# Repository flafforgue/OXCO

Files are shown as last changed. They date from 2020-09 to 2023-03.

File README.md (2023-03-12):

# OXCO
Kicad project for 10MHz OXCO with frequency divider and multiplier
outputs 25 Mhz, 10 Mhz, 1 Mhz, 10 Khz,1 kHz ( yes 100khz is ommited but i have not enougth space on board :) 

there are 4 x 10 Mhz outputs , grouped by 2 in oposite phase
what can be done is for 2 installing filter as indicated and for the two other replacing inductance 
and output capacity by strap and not installing filter capacity for having square waves output.

composed of 2 boards
first with OXCO and precision voltage generator and buffered 10 MHz outputs
second with ICS511 multiplier ( 2.5 so 25 MHz outputs ) and 74LS390  dividers

all outputs are 50 Ohms, buffered with 3 x 74HC04 inverter and filter to keep only sine wave



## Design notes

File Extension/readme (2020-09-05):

extention board with dividers and multiplier module

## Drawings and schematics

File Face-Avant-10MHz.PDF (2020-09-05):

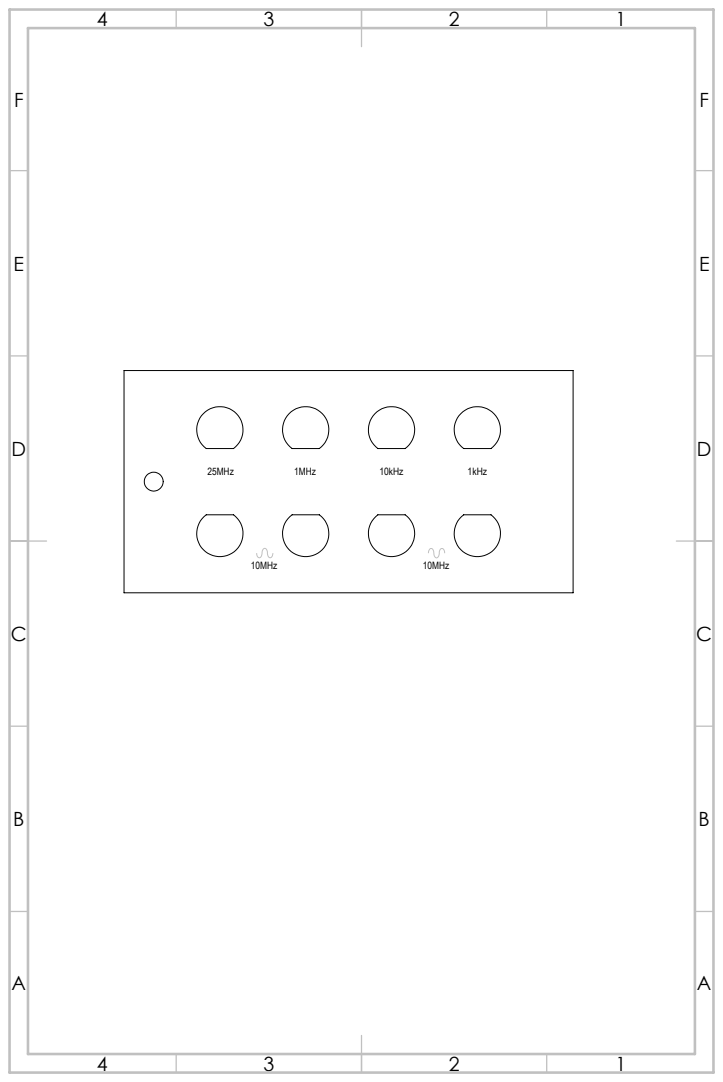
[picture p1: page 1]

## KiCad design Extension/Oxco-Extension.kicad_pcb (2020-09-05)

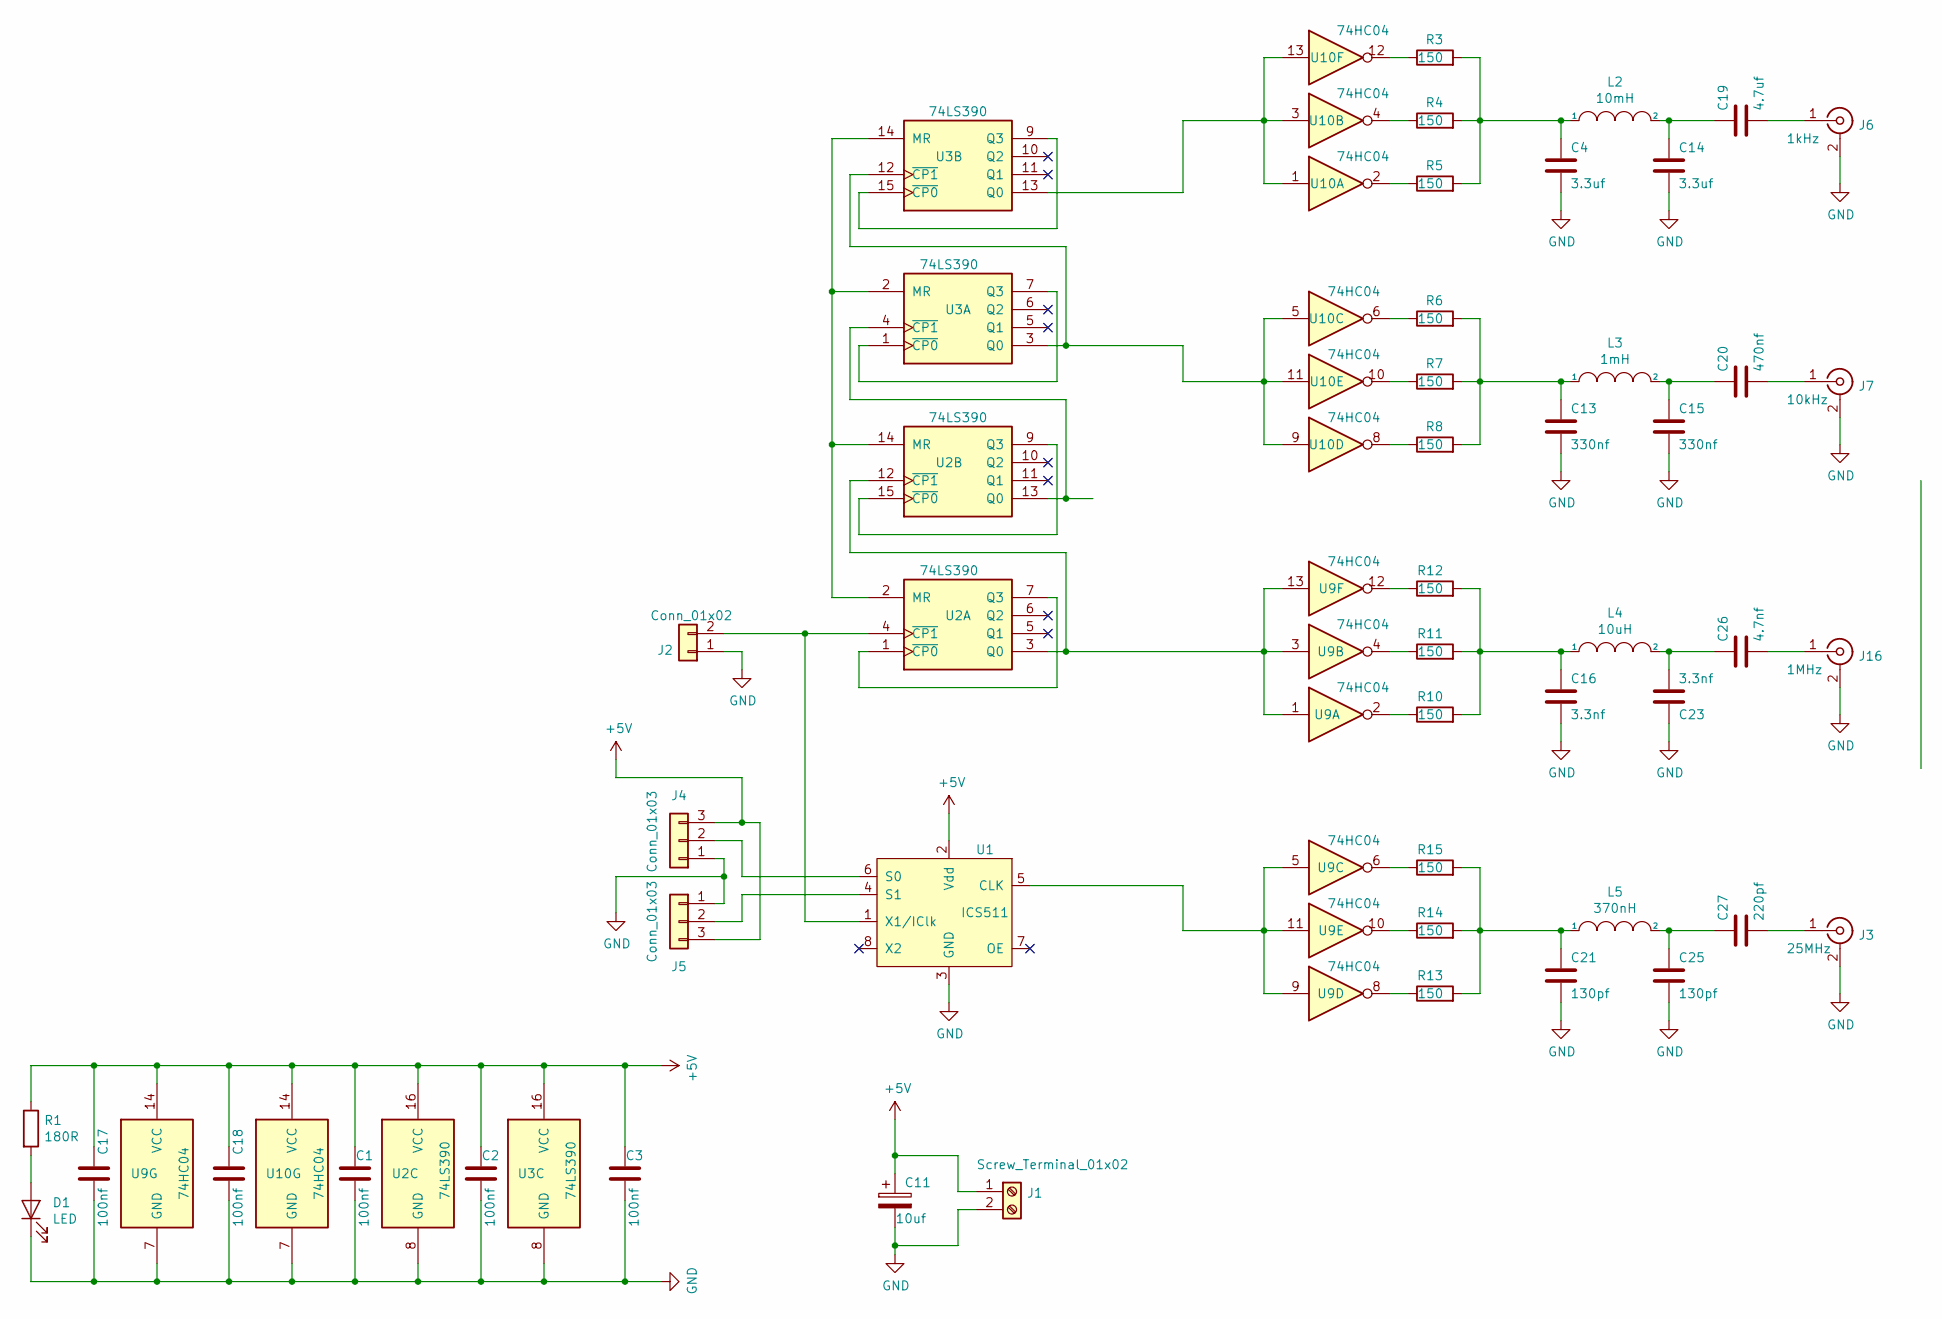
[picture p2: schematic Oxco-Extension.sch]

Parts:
C1, C2, C3, C17, C18: 100nf; Cx
C4, C14: 3.3uf; C_Disc_D5.0mm_W2.5mm_P5.00mm
C11: 10uf; CP_Radial_D7.5mm_P2.50mm
C13, C15: 330nf; C_Disc_D5.0mm_W2.5mm_P5.00mm
C16, C23: 3.3nf; C_Disc_D5.0mm_W2.5mm_P5.00mm
C19: 4.7uf; C_Disc_D5.0mm_W2.5mm_P5.00mm
C20: 470nf; C_Disc_D5.0mm_W2.5mm_P5.00mm
C21, C25: 130pf; C_Disc_D5.0mm_W2.5mm_P5.00mm
C26: 4.7nf; C_Disc_D5.0mm_W2.5mm_P5.00mm
C27: 220pf; C_Disc_D5.0mm_W2.5mm_P5.00mm
D1: LED; LED_D5.0mm_Clear
J1: Screw_Terminal_01x02; TerminalBlock_RND_205-00287_1x02_P5.08mm_Horizontal
J2: Conn_01x02; PinSocket_1x02_P2.54mm_Vertical
J3: 25MHz; BNC_Amphenol_B6252HB-NPP3G-50_Horizontal
J4, J5: Conn_01x03; Con_1x03_P2.54mm
J6: 1kHz; BNC_Amphenol_B6252HB-NPP3G-50_Horizontal
J7: 10kHz; BNC_Amphenol_B6252HB-NPP3G-50_Horizontal
J16: 1MHz; BNC_Amphenol_B6252HB-NPP3G-50_Horizontal
L2: 10mH; Rx
L3: 1mH; Rx
L4: 10uH; Rx
L5: 370nH; Rx
R1: 180R; H-Rx
R3, R4, R5, R6, R7, R8, R10, R11, R12, R13, R14, R15: 150; H-Rx
U1: ICS511; SOIC-8_3.9x4.9mm_P1.27mm
U2, U3: 74LS390; DIP-16_W7.62mm_Socket_LongPads
U9, U10: 74HC04; DIP-14_W7.62mm_Socket_LongPads

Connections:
+5V: C1.1, C2.1, C3.1, C11.1, C17.1, C18.1, J1.1, J4.3, J5.3, R1.1, U1.2 (Vdd), U2.16 (VCC), U3.16 (VCC), U9.14 (VCC), U10.14 (VCC)
GND: C1.2, C2.2, C3.2, C4.2, C11.2, C13.2, C14.2, C15.2, C16.2, C17.2, C18.2, C21.2, C23.1, C25.2, D1.1 (K), J1.2, J2.1, J3.2 (Ext), J4.1, J5.1, J6.2 (Ext), J7.2 (Ext), J16.2 (Ext), U1.3 (GND), U2.8 (GND), U3.8 (GND), U9.7 (GND), U10.7 (GND)
unnamed: C4.1, L2.1, R3.2, R4.2, R5.2
unnamed: C13.1, L3.1, R6.2, R7.2, R8.2
unnamed: C14.1, C19.1, L2.2
unnamed: C15.1, C20.1, L3.2
unnamed: C16.1, L4.1, R10.2, R11.2, R12.2
unnamed: C19.2, J6.1 (In)
unnamed: C20.2, J7.1 (In)
unnamed: C21.1, L5.1, R13.2, R14.2, R15.2
unnamed: C23.2, C26.1, L4.2
unnamed: C25.1, C27.1, L5.2
unnamed: C26.2, J16.1 (In)
unnamed: C27.2, J3.1 (In)
unnamed: D1.2 (A), R1.2
unnamed: J2.2, U1.1 (X1/IClk), U2.4 (~CP1)
unnamed: J4.2, U1.6 (S0)
unnamed: J5.2, U1.4 (S1)
unnamed: R3.1, U10.12
unnamed: R4.1, U10.4
unnamed: R5.1, U10.2
unnamed: R6.1, U10.6
unnamed: R7.1, U10.10
unnamed: R8.1, U10.8
unnamed: R10.1, U9.2
unnamed: R11.1, U9.4
unnamed: R12.1, U9.12
unnamed: R13.1, U9.8
unnamed: R14.1, U9.10
unnamed: R15.1, U9.6
unnamed: U1.5 (CLK), U9.5, U9.9, U9.11
unnamed: U2.1 (~CP0), U2.7 (Q3)
unnamed: U2.3 (Q0), U2.12 (~CP1), U9.1, U9.3, U9.13
unnamed: U2.13 (Q0), U3.4 (~CP1)
unnamed: U2.2 (MR), U2.14 (MR), U3.2 (MR), U3.14 (MR)
unnamed: U2.9 (Q3), U2.15 (~CP0)
unnamed: U3.1 (~CP0), U3.7 (Q3)
unnamed: U3.9 (Q3), U3.15 (~CP0)
unnamed: U3.13 (Q0), U10.1, U10.3, U10.13
unnamed: U3.3 (Q0), U3.12 (~CP1), U10.5, U10.9, U10.11

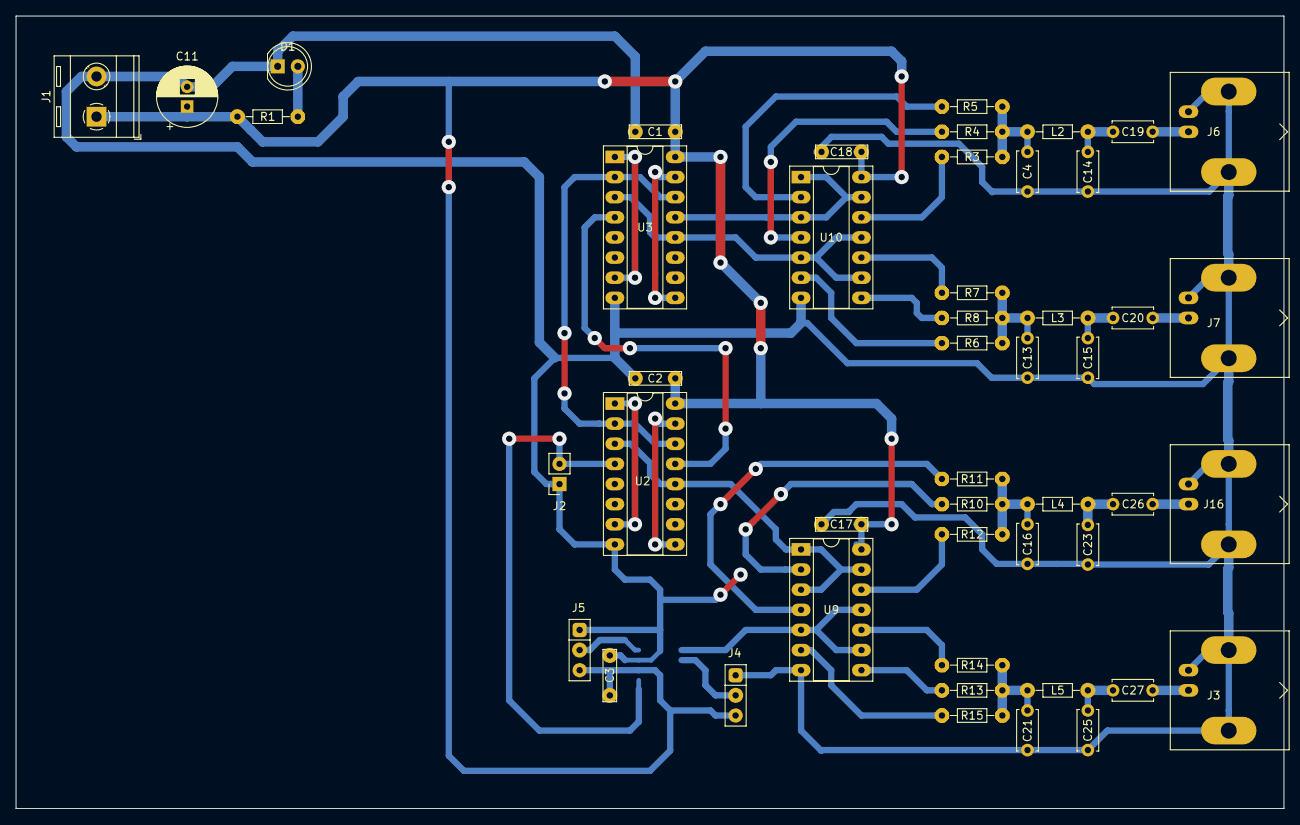
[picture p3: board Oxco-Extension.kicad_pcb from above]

Board: 2 copper layers, 160.0 x 100.0 mm, 49 parts (1 on the bottom side), 40 nets.
